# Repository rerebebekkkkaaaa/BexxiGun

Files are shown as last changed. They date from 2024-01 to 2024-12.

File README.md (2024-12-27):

arduino ide: 
-board:"ESP32 Dev Module" oder "AI Thinker ESP32-CAM"
-Port(linux):"/dev/ttyUSB0"

flashen:
1.flash pin einstecken
2.power aus
3.power an
4.upload
5.flash pin aus
6.power aus
7.power an 

LIBS:
FastLed = 3.9.7
https://github.com/me-no-dev/ESPAsyncWebServer = 3.4.0
 https://github.com/ayushsharma82/ElegantOTA = 3.1.6
ArduinoJson(https://arduinojson.org/) =7.2.1

Partition Scheme (for OTA!!!!):
Minimal SPIFFSS

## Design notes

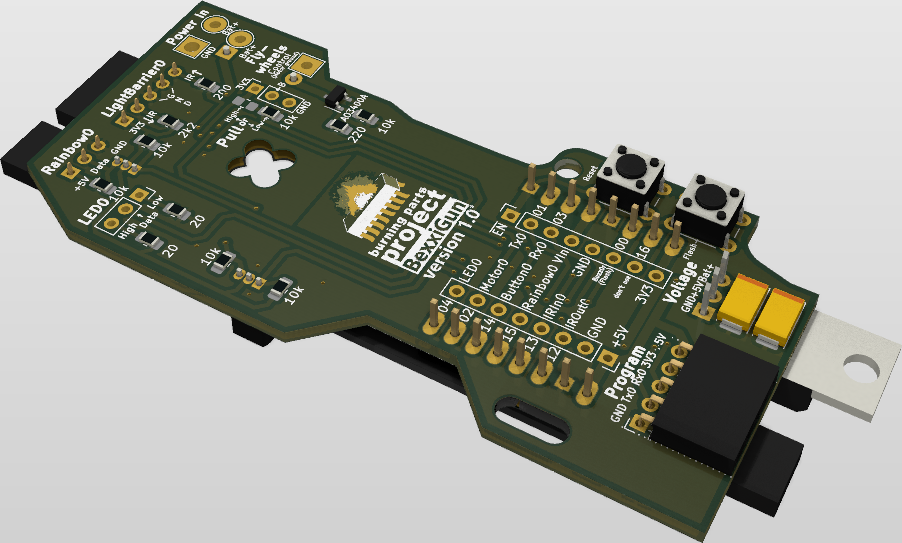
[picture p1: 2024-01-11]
pcb/board_back-1.png

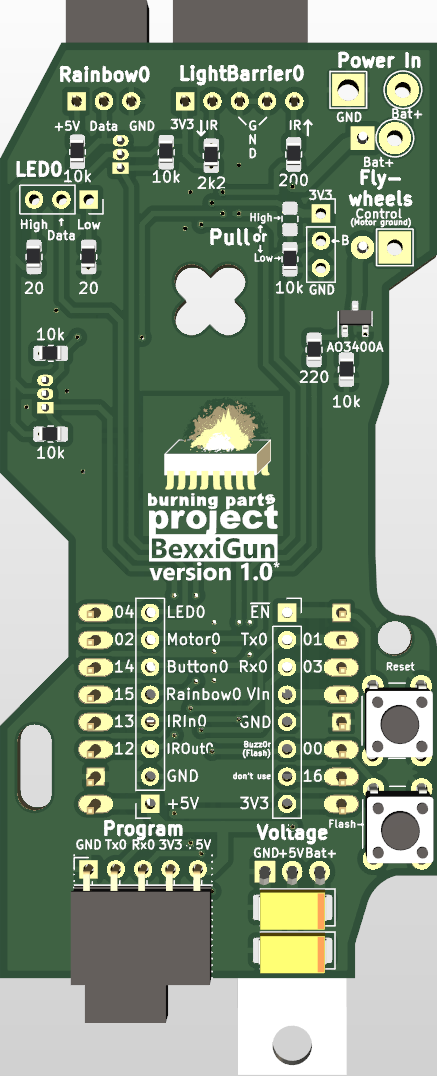
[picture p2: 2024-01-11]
pcb/board_front.png

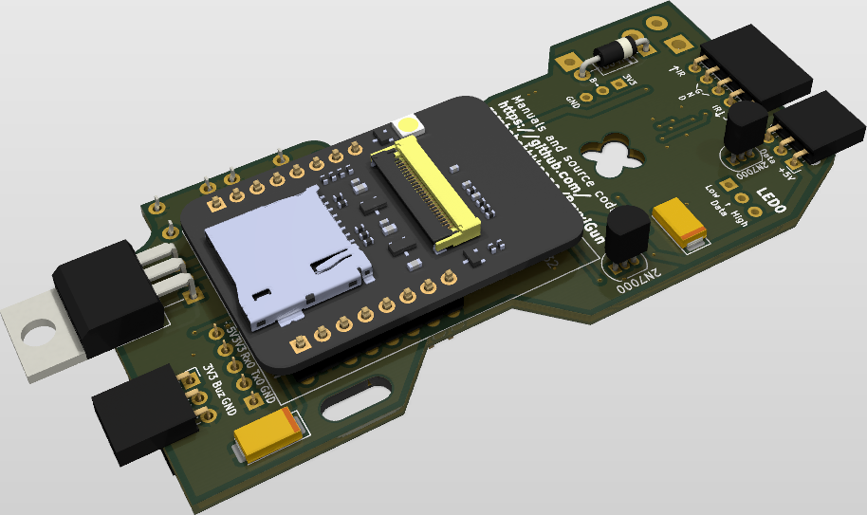
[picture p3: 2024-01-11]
pcb/board_front-1.png

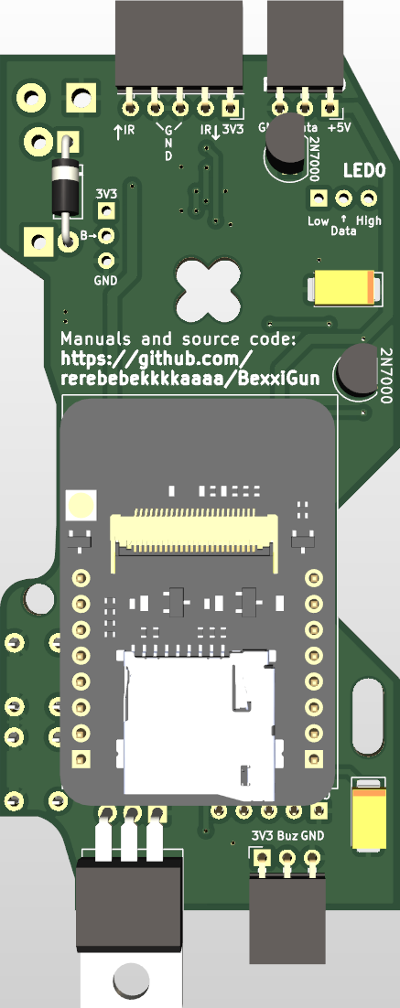
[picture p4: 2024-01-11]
pcb/board_back.png

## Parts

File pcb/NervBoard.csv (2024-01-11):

Ref | Qnty | MPN | Value | Description
C1, C2, C3, C4 | 4 | T491U106K020AT | 10uF | Unpolarized capacitor
D1 | 1 | TSAL6200 | TSAL6200 | 950nm IR-LED, 5mm
D2 | 1 | 1N4004-B | 1N4004 | 400V 1A General Purpose Rectifier Diode, DO-41
Flash0 | 1 | TS02-66-43-BK-160-SCR-D |  | Push button switch, generic, two pins
J1, J2 | 2 | SL-108-TT-11 |  | Generic connector, single row, 01x08, script generated
J_Buzzor_0 | 1 | BG302-03-A-L-G |  | Generic connector, single row, 01x03, script generated
J_Prog0 | 1 | BG302-05-A-L-G |  | Generic connector, single row, 01x05, script generated
LightBarrier0 | 1 | BG302-06-A-L-G |  | Generic connector, single row, 01x05, script generated
Q0, Q2 | 2 | 2N7000TA | 2N7000 | 0.2A Id, 200V Vds, N-Channel MOSFET, 2.6V Logic Level, TO-92
Q3 | 1 | AO3400A | AO3400A | 30V Vds, 5.7A Id, N-Channel MOSFET, SOT-23
R_Down_But0 | 1 | RT0805FRE0710KL | 10k | Resistor
R_Down_LED0 | 1 | RT0805FRE0720RL | 20 | Resistor
R_Down_Motor1 | 1 | RT0805FRE0710KL | 10k | Resistor
R_Filter_Motor0 | 1 | RT0805FRE07220RL | 220 | Resistor
R_IRIn_0 | 1 | RT0805FRE072K2L | 2k2 | Resistor
R_IROut_0 | 1 | RT0805FRE07200RL | 200 | Resistor
R_Lvl_30, R_Lvl_31, R_Lvl_50, R_Lvl_51 | 4 | RT0805FRE0710KL | 10k | Resistor
R_Up_LED0 | 1 | RT0805FRE0720RL | 20 | Resistor
Rainbow0 | 1 | BG302-03-A-L-G |  | Generic connector, single row, 01x03, script generated
Reset0 | 1 | TS02-66-43-BK-160-SCR-D |  | Push button switch, generic, two pins
U1 | 1 | ESP32-CAM | ESP32-CAM
U2 | 1 | LM1085IT-5.0/NOPB | LM1085-5.0 | 3A 25V Linear Regulator, Fixed Output 5.0V, TO-220/TO-263
U3 | 1 | TSSP4038 | TSSP4038 | IR Receiver Modules for Remote Control Systems

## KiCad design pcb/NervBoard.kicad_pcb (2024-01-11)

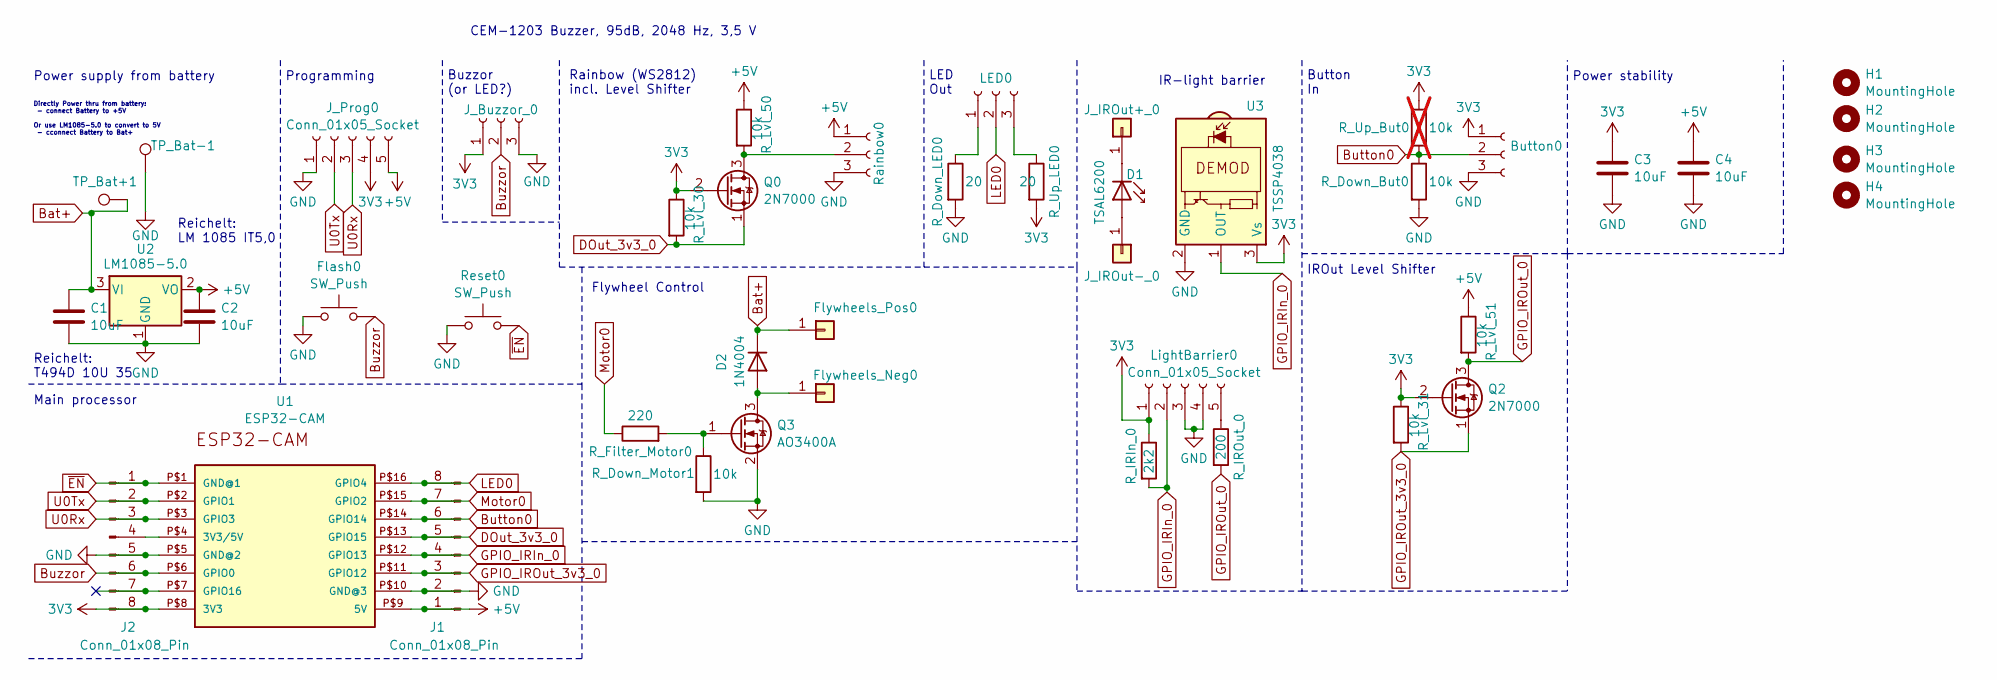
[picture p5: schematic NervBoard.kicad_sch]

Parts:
Button0: Conn_01x03_Socket; PinSocket_1x03_P2.54mm_Vertical; MPN BG302-03-A-L-G
C1, C2, C3, C4: 10uF; CP_EIA-6032-15_Kemet-U_Pad2.25x2.35mm_HandSolder; MPN T491U106K020AT
D1: TSAL6200; MPN TSAL6200
D2: 1N4004; D_DO-41_SOD81_P10.16mm_Horizontal; MPN 1N4004-B
Flash0: SW_Push; SW_PUSH_6mm_H4.3mm; MPN TS02-66-43-BK-160-SCR-D
Flywheels_Neg0: Conn_01x01; TestPoint_THTPad_3.0x3.0mm_Drill1.5mm
Flywheels_Pos0: Conn_01x01; TestPoint_THTPad_D3.0mm_Drill1.5mm
H1: MountingHole; MountingHole_3.2mm_M3
H2, H3, H4: MountingHole; MountingHole__Langloch_3.2mm_M3
J1, J2: Conn_01x08_Pin; PinSocket_1x08_P2.54mm_Vertical; MPN SL-108-TT-11
J_Buzzor_0: Conn_01x03_Socket; PinSocket_1x03_P2.54mm_Horizontal_NoPrint; MPN BG302-03-A-L-G
J_IROut+_0: (no value)
J_IROut-_0: (no value)
J_Prog0: Conn_01x05_Socket; PinSocket_1x05_P2.54mm_Horizontal_NoPrint; MPN BG302-05-A-L-G
LED0: Conn_01x03_Socket; PinSocket_1x03_P2.54mm_Vertical; MPN BG302-03-A-L-G
LightBarrier0: Conn_01x05_Socket; PinSocket_1x05_P2.54mm_Horizontal_NoPrint; MPN BG302-05-A-L-G
Q0, Q2: 2N7000; TO-92_Inline; MPN 2N7000TA
Q3: AO3400A; SOT-23; MPN AO3400A
R_Down_But0: 10k; R_0805_2012Metric_Pad1.20x1.40mm_HandSolder; MPN RT0805FRE0710KL
R_Down_LED0: 20; R_0805_2012Metric_Pad1.20x1.40mm_HandSolder; MPN RT0805FRE0720RL
R_Down_Motor1: 10k; R_0805_2012Metric_Pad1.20x1.40mm_HandSolder; MPN RT0805FRE0710KL
R_Filter_Motor0: 220; R_0805_2012Metric_Pad1.20x1.40mm_HandSolder; MPN RT0805FRE07220RL
R_IRIn_0: 2k2; R_0805_2012Metric_Pad1.20x1.40mm_HandSolder; MPN RT0805FRE072K2L
R_IROut_0: 200; R_0805_2012Metric_Pad1.20x1.40mm_HandSolder; MPN RT0805FRE07200RL
R_Lvl_30, R_Lvl_31, R_Lvl_50, R_Lvl_51: 10k; R_0805_2012Metric_Pad1.20x1.40mm_HandSolder; MPN RT0805FRE0710KL
R_Up_But0: 10k; R_0805_2012Metric_Pad1.20x1.40mm_HandSolder; MPN RT0805FRE0710KL; not fitted
R_Up_LED0: 20; R_0805_2012Metric_Pad1.20x1.40mm_HandSolder; MPN RT0805FRE0720RL
Rainbow0: Conn_01x03_Socket; PinSocket_1x03_P2.54mm_Horizontal_NoPrint; MPN BG302-03-A-L-G
Reset0: SW_Push; SW_PUSH_6mm_H4.3mm; MPN TS02-66-43-BK-160-SCR-D
TP_Bat+1: TestPoint; TestPoint_THTPad_D3.0mm_Drill1.5mm
TP_Bat-1: TestPoint; TestPoint_THTPad_3.0x3.0mm_Drill1.5mm
U1: ESP32-CAM; MPN ESP32-CAM
U2: LM1085-5.0; TO-220-3_Horizontal_TabDown; MPN LM1085IT-5.0/NOPB
U3: TSSP4038; MPN TSSP4038

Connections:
3V3: Button0.1, C3.1, J2.8, J_Buzzor_0.1, J_Prog0.4, LightBarrier0.1, Q0.2 (G), Q2.2 (G), R_IRIn_0.1, R_Lvl_30.1, R_Lvl_31.1, R_Up_But0.1, R_Up_LED0.2, U1.P$8 (3V3), U3.3 (Vs)
+5V: C2.1, C4.1, J1.1, J_Prog0.5, R_Lvl_50.1, R_Lvl_51.1, Rainbow0.1, U1.P$9 (5V), U2.2 (VO)
Bat+: C1.1, D2.1 (K), Flywheels_Pos0.1, TP_Bat+1.1, U2.3 (VI)
Button0: Button0.2, J1.6, R_Down_But0.1, R_Up_But0.2, U1.P$14 (GPIO14)
Buzzor: Flash0.2, J2.6, J_Buzzor_0.2, U1.P$6 (GPIO0)
DOut_3v3_0: J1.5, Q0.1 (S), R_Lvl_30.2, U1.P$13 (GPIO15)
GND: Button0.3, C1.2, C2.2, C3.2, C4.2, Flash0.1, J1.2, J2.5, J_Buzzor_0.3, J_Prog0.1, LightBarrier0.3, LightBarrier0.4, Q3.2 (S), R_Down_But0.2, R_Down_LED0.2, R_Down_Motor1.2, Rainbow0.3, Reset0.1, TP_Bat-1.1, U1.P$5 (GND@2), U1.P$10 (GND@3), U2.1 (GND), U3.2 (GND)
GPIO_IRIn_0: J1.4, LightBarrier0.2, R_IRIn_0.2, U1.P$12 (GPIO13), U3.1 (OUT)
GPIO_IROut_0: Q2.3 (D), R_IROut_0.2, R_Lvl_51.2
GPIO_IROut_3v3_0: J1.3, Q2.1 (S), R_Lvl_31.2, U1.P$11 (GPIO12)
LED0: J1.8, LED0.2, U1.P$16 (GPIO4)
Motor0: J1.7, R_Filter_Motor0.1, U1.P$15 (GPIO2)
unnamed: D1.1 (K), J_IROut+_0.1
unnamed: D1.2 (A), J_IROut-_0.1
unnamed: D2.2 (A), Flywheels_Neg0.1, Q3.3 (D)
unnamed: J2.4, U1.P$4 (3V3/5V)
unnamed: LED0.1, R_Down_LED0.1
unnamed: LED0.3, R_Up_LED0.1
unnamed: LightBarrier0.5, R_IROut_0.1
unnamed: Q0.3 (D), R_Lvl_50.2, Rainbow0.2
unnamed: Q3.1 (G), R_Down_Motor1.1, R_Filter_Motor0.2
U0Rx: J2.3, J_Prog0.3, U1.P$3 (GPIO3)
U0Tx: J2.2, J_Prog0.2, U1.P$2 (GPIO1)
~EN: J2.1, Reset0.2, U1.P$1 (GND@1)

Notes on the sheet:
Reichelt: T494D 10U 35
Flywheel Control
Programming
Main processor
Button In
LED Out
Power stability
IROut Level Shifter
Power supply from battery
Directly Power thru from battery: - connect Battery to +5V Or use LM1085-5.0 to convert to 5V - cconnect Battery to Bat+
Reichelt: LM 1085 IT5,0
CEM-1203 Buzzer, 95dB, 2048 Hz, 3,5 V
Buzzor (or LED?)
Rainbow (WS2812) incl. Level Shifter
IR-light barrier

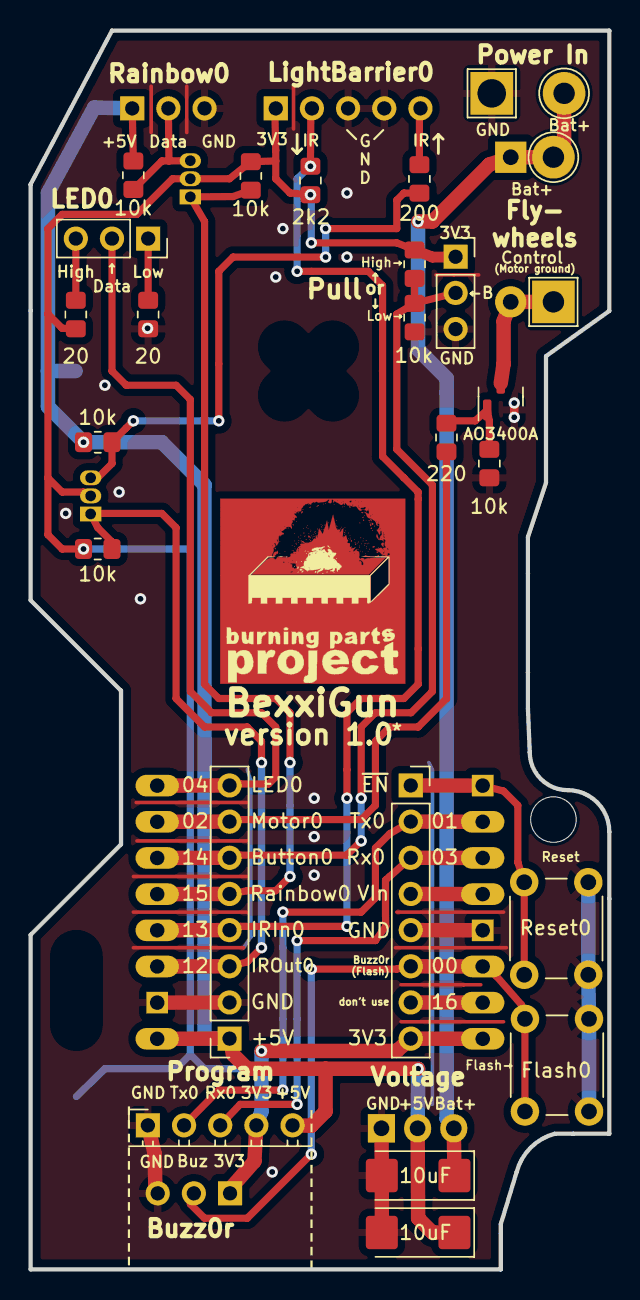
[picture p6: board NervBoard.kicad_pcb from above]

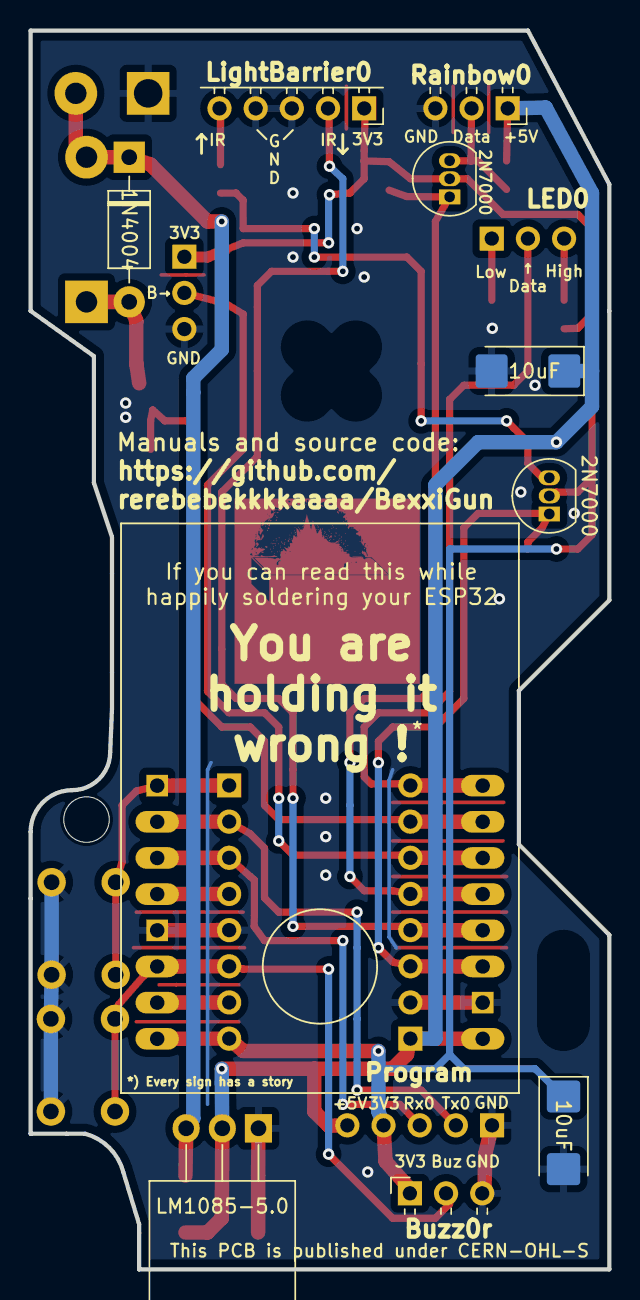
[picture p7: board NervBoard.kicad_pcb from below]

Board: 2 copper layers, 40.6 x 87.0 mm, 40 parts (10 on the bottom side), 22 nets.

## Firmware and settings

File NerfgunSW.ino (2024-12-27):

/*
BexxiGun 0.1 (Un)locked SW
Main Control File & Pins
*/
#include <Arduino.h>
#include <FastLED.h>
#include <WiFi.h>
#include <ElegantOTA.h>
#include <AsyncTCP.h>
#include <ESPAsyncWebServer.h>
#include "pitches.h"
#include "Wificredentials.h"


//Pins
#define DATA_PIN 15
#define BUZZ0R_PIN  0
#define FLY_PIN 2
#define BUTTON_PIN 14
#define ESPLED_PIN 4
#define IROUT_PIN 12
#define IRIN_PIN 13
#define RED_LED 33

enum GunState {
  PARTY_MODE = 0,
  DEATH_MODE = 1,
  SNEAK_MODE = 2,
  TV_B_GONE_MODE = 3
};
volatile GunState gunCur;

// Motor Globals
void MotorControl(void * param);
const int freqMotor = 2000;
const int resMotor = 8;
enum MotorState {
  MOTOR_OFF = 0,
  MOTOR_STARTING = 1,
  MOTOR_SPINNING = 2,
  MOTOR_FREEFLY = 3
};
volatile MotorState mostCur;


// Pew Pew Globals
void PewPewControl(void * param);
const int freqBuzz0r = 2000;
const int resBuzz0r = 8;

//LightBarrier Globals
const int freqBarrier = 38000;
const int resBarrier = 8;
volatile bool wasLightBarrierTriggered=false;
volatile bool LightBarrierBlingBling=false;
volatile bool LightBarrierPewPew=false;
volatile int starttime =0;
volatile int endtime=0;
volatile double dartspeed=0.0;
volatile double maxdartspeed=0.0;
volatile double mindartspeed=0.0;
#define SPEEDDIVISOR 22.22 //calculated using scientific methods


// Bling Bling Globals
void BlingBlingControl(void * param);
#define NUM_LEDS 7
CRGB leds[NUM_LEDS];

// Button Globals
void ButtonControl(void  * param);
volatile uint32_t usLastShortPress = 0;
volatile uint32_t usLastLongPress = 0;

//Webserver globals
volatile uint32_t usLastWifiControl = 0;
volatile int colorsetup=-1;
AsyncWebServer server(80);

// Task handles
TaskHandle_t taskButtonPull;
TaskHandle_t taskMotorControl;
TaskHandle_t taskPewPew;
TaskHandle_t taskBlingBling;
TaskHandle_t taskWiwiFifi;

//global interrupt handlers
void ARDUINO_ISR_ATTR isrLightBarrier() {

  LightBarrierBlingBling=true;
  LightBarrierPewPew=true;
  //BOLT START
  if(!wasLightBarrierTriggered){
    starttime=micros();
    wasLightBarrierTriggered=true;

  }
  //BOLT END
  else {
    endtime=micros();
    wasLightBarrierTriggered=false;
  }
}

//global functions
const char* MotorStateToString(MotorState m){
  switch(m){
    case MOTOR_OFF:
      return "MOTOR OFF";
    case MOTOR_STARTING:
      return "MOTOR STARTING";
    case MOTOR_SPINNING:
      return "MOTOR SPINNING";
    case MOTOR_FREEFLY:
      return "MOTOR FREEFLY";   
  }
  return "NONE";
}
const char* GunStateToString(GunState g){
  switch(g){
    case PARTY_MODE:
      return "PARTY MODE";
    case DEATH_MODE:
      return "DEATH MODE";
    case SNEAK_MODE:
      return "SNEAK MODE";
  }
  return "NONE";
}
void DartSpeed(int start, int end){
  Serial.printf("%i",wasLightBarrierTriggered);
  if(!wasLightBarrierTriggered){
    Serial.printf("start:%d",start);
    Serial.printf("end:%d",end);
    if(end > start){

      Serial.printf("time:%d",end-start);
      dartspeed= (end-start)/ SPEEDDIVISOR;
      if(dartspeed > maxdartspeed){
        maxdartspeed = dartspeed;
      }
      else if(dartspeed < mindartspeed || mindartspeed == 0.0){
        mindartspeed = dartspeed;
      }
    }
  }
}

void setup() { 
  bool isPWMMotorOK=false;
  bool isPWMBuzz0rOK=false;
  bool isPWMBarrierOK=false;

  Serial.begin(115200);
  delay(250); //Let serial settle a bit

  pinMode(ESPLED_PIN, OUTPUT);
  pinMode(FLY_PIN, OUTPUT);
  pinMode(BUTTON_PIN,INPUT);
  pinMode(IROUT_PIN, OUTPUT);
  pinMode(IRIN_PIN,INPUT);
  
  pinMode(BUZZ0R_PIN,OUTPUT);
  pinMode(RED_LED,OUTPUT);
  pinMode(DATA_PIN,OUTPUT);



  //set up the motor 
  isPWMMotorOK=ledcAttach(FLY_PIN, freqMotor, resMotor);
  Serial.printf("PWM Motor: %d\n", isPWMMotorOK);

  //set up the nerv buzz0r
  isPWMBuzz0rOK=ledcAttach(BUZZ0R_PIN, freqBuzz0r, resBuzz0r);
  Serial.printf("PWM Buzz0r: %d\n", isPWMBuzz0rOK);

  //set up the  Lightbarrier PWM LED
  //isPWMBarrierOK=ledcSetup(pwmChanBarrier, freqBarrier, resBarrier);
  //ledcAttachPin(IROUT_PIN, pwmChanBarrier);
  //ledcWrite(pwmChanBarrier, 128);
  //Serial.printf("PWM Lightbarrier: %d\n", isPWMBarrierOK);
  isPWMBarrierOK = LightBarrierSetup();

  //set up the rgb
  FastLED.addLeds<NEOPIXEL, DATA_PIN>(leds, NUM_LEDS);  // GRB ordering is assumed

  //setup wifi
  WiFi.mode(WIFI_AP);
  Serial.print("Connecting to");
  Serial.println(SSID);
  WiFi.softAP(SSID, PASSWORD);


  Serial.print("AP IP address: ");

  Serial.println(WiFi.softAPIP());

  delay(250);
   xTaskCreatePinnedToCore(
                    ButtonControl,   /* Task function. */
                    "ButtonPuller",     /* name of task. */
                    1024,       /* Stack size of task */
                    NULL,        /* parameter of the task */
                    1,           /* priority of the task */
                    &taskButtonPull,      /* Task handle to keep track of created task */
                    0);          /* pin task to core 0 */
   xTaskCreatePinnedToCore(
                    MotorControl,   /* Task function. */
                    "MotorControl",     /* name of task. */
                    10000,       /* Stack size of task */
                    NULL,        /* parameter of the task */
                    1,           /* priority of the task */
                    &taskMotorControl,      /* Task handle to keep track of created task */
                    0);          /* pin task to core 0 */
  xTaskCreatePinnedToCore(
                    PewPewControl,   /* Task function. */
                    "PewPewControl",     /* name of task. */
                    10000,       /* Stack size of task */
                    NULL,        /* parameter of the task */
                    1,           /* priority of the task */
                    &taskPewPew,      /* Task handle to keep track of created task */
                    0);          /* pin task to core 1 */
  xTaskCreatePinnedToCore(
                    BlingBlingControl,   /* Task function. */
                    "BlingBlingControl",     /* name of task. */
                    10000,       /* Stack size of task */
                    NULL,        /* parameter of the task */
                    1,           /* priority of the task */
                    &taskBlingBling,      /* Task handle to keep track of created task */
                    1);          /* pin task to core 1 */
  xTaskCreatePinnedToCore(
                    WiwiFifiControl,   /* Task function. */
                    "WiwiFifiControl",     /* name of task. */
                    10000,       /* Stack size of task */
                    NULL,        /* parameter of the task */
                    1,           /* priority of the task */
                    &taskWiwiFifi,      /* Task handle to keep track of created task */
                    1);          /* pin task to core 1 */
  //Ready the light barrier input
  attachInterrupt(IRIN_PIN, isrLightBarrier, CHANGE);

}

void loop() {
  digitalWrite(RED_LED, HIGH);
  delay(5000);
  digitalWrite(RED_LED, LOW);
  delay(5000);

}

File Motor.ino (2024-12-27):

/*
BexxiGun 0.1 (Un)locked SW
Bling Bling Control File
*/

// M O T O R   C O N T R O L
void MotorControl(void * param) {
  uint32_t dutyCur=0;
  
  //Store last run so we can check if something happend since then
  uint32_t uLastRun=1;

  for(;;) {
    uint32_t uCurRun=millis();
    
    switch(mostCur) {
      case MOTOR_OFF:
        //Wait for LongPress to turn motor on
        if(uLastRun<usLastLongPress) {
          mostCur=MOTOR_STARTING;
          dutyCur=0;
          Serial.write("Starting motor");
        }
        break;
      case MOTOR_STARTING:
        //increase motor speed for 254 * 10 ms = 2.54seconds
        if(dutyCur<255) {
          ledcWrite(FLY_PIN, dutyCur);
          dutyCur+=1;
        } else {
          mostCur=MOTOR_SPINNING;
          gunCur=DEATH_MODE;
          ledcWrite(FLY_PIN, 255);
        }
        break;
      case MOTOR_SPINNING:
        if(uLastRun<usLastLongPress) {
          mostCur=MOTOR_FREEFLY;
          gunCur=PARTY_MODE;
          dutyCur=0;
          Serial.write("Stoping motor");
        }
        break;
      case MOTOR_FREEFLY:
        if(dutyCur==0) {
          ledcWrite(FLY_PIN, 0);
        }
        dutyCur+=1;
        if(dutyCur >= 400) {
          mostCur=MOTOR_OFF;
        }
        break;
    }
    uLastRun=uCurRun;
    delay(10); 
  }
}

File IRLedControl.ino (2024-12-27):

/*
BexxiGun 0.1 (Il)legal Instructions SW
IRLed Control File
*/

#include "TVBarrierCodes.h"
#include <Arduino.h>

bool LightBarrierSetup() {
  bool isPWMBarrierOK=ledcAttach(IROUT_PIN, freqBarrier, resBarrier);
  ledcWrite(IROUT_PIN, 128);
  Serial.printf("PWM Lightbarrier: %d\n", isPWMBarrierOK);
  return isPWMBarrierOK;
}

void delay_ten_us(uint16_t us) {
  delayMicroseconds(us*10);
}

void xmitCodeElement(uint16_t ontime, uint16_t offtime, uint8_t PWM_code)
{
  if(PWM_code)
    analogWrite(IROUT_PIN, 512);
  else
    digitalWrite(IROUT_PIN, HIGH);
  delay_ten_us(ontime);
  digitalWrite(IROUT_PIN, LOW);
  delay_ten_us(offtime);
}

void sendTVbGoneCodes(){
  detachInterrupt(IRIN_PIN);
  int sz=sizeof(codes_eu)/sizeof(codes_eu[0])/3;
  for(int i=0 ;i<sz;i++) {
    if(mostCur == MOTOR_OFF){
      SolidColorMode(CHSV(85, 255, 255));
      const int *cc=codes_eu+3*i;
      int freq=pgm_read_dword(cc+0);
      const unsigned short *code=codes2_eu+pgm_read_dword(cc+2);
      analogWriteFrequency(IROUT_PIN, freq);

      for (int k=0;k<pgm_read_dword(cc+1);k+=2)
        xmitCodeElement(pgm_read_word(code+k), pgm_read_word(code+k+1), (freq!=0));  

      delay(130);
      SolidColorMode(CHSV(214, 255, 255));
    } else {
      // Stop tvbgone code send here to avoid problems with dart recognition
      LightBarrierSetup();
      return;
    }
  }
  LightBarrierSetup();
  SolidColorMode(CHSV(42, 255, 255));
  //Ready the light barrier input
  attachInterrupt(IRIN_PIN, isrLightBarrier, CHANGE);



}

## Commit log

2023-12-29 Not working interrupt initial state
    [NerfgunSW.ino]
2023-12-29 Working version flywheel button
2023-12-29 not working flywheel power up stuff
    [NerfgunSW.ino]
2023-12-29 Moved button pull and motor control into tasks
2023-12-30 I fixed the code someone else messed upgit add *111git add *elfgit add *
    [NerfgunSW.ino]
2023-12-31 clean code und so refactoring kram
2024-01-02 Added a new pcb version. Fixed some flawes from v0.1, moved GPIOs, stailized power supply, added additional level shifters
    [NervBoard.kicad_pcb, NervBoard.kicad_sch]
2024-01-05 Added improved version of pcb v0.2 with full rewiring, focus on a more stable ground and broader wires.
    [NervBoard.kicad_pcb]
2024-01-11 Improved board to a stable version
    [NervBoard.csv, NervBoard.kicad_pcb, NervBoard.kicad_sch]
2024-01-11 Added a LICENSE to make PCB re-usable
    [NervBoard.kicad_pcb]
2024-01-31 Added support (very lazy, indeed) for lightbarrier/bolt detection
2024-02-03 working lightbarrier but unstable dart-speed measurement
    [BlingBling.ino, NerfgunSW.ino, PewPew.ino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]

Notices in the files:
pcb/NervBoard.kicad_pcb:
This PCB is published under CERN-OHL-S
